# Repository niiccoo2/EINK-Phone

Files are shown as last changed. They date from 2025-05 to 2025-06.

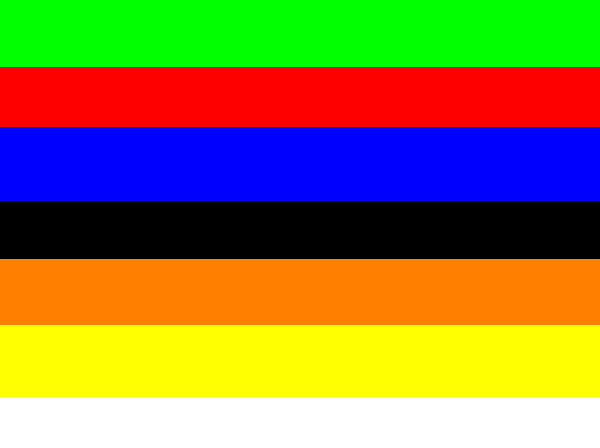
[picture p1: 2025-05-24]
pic/Color7.bmp

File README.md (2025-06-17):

[Google Doc Notes Link](https://docs.google.com/document/d/1l_P9BNs8-fzjLHjxsxwmtQVHC8uADbmZvHsqvaNpZNw/edit?usp=sharing)
[Docs link for pico version](https://docs.google.com/document/d/1WdVnLDW4LZ5mjuCLy1hVp1n7MNubI6F_SzgGbY42siQ/edit?usp=sharing)

### Sunday, May 11:
* Saw the light phone 3 and thought it cost too much.
* Started thinking about how I could make my own

*30 minutes*

### Monday, May 12:
* Decided to use a pi zero w
* Ordered a SIM7600A-H cell modem.

*30 minutes*

### Thursday, May 15:
* Got modem and started working on the python code that sends texts
* Found out that verizon does not work with my modem
* Thought that ssh was slow bc I was using a pi zero *My fault not true*
* Ordered rpi zero 2w
* Ordered a new sim card
* Ordered a 4.2in Waveshare E-Ink screen

*5 hours*

### Saturday, May 17:
* Started figuring out how to use the display drivers in python
* Got the demo working [Photo](https://photos.app.goo.gl/T3E3aoRRHVqETAhi7)
* Got it so that it would display a random number
* Figured out how to use partial refreshes

*4 hours*

### Sunday, May 18:
*Got a basic homescreen working it will dynamically display apps from a dictionary

*3 hours*

### Tuesday, May 20:
*Added a cursor so you can use input statements to move up and down on the screen and select an app. [Photo](https://photos.app.goo.gl/G6LSFMMkUEmNv3iD8)

*3 hours*

### Thursday, May 22:
* Set up new sim card
* FINALLY got the modem working for texting and data
* Hardwired the usb connection because the cable was too big
* [Blog Post](https://niiccoo2.xyz/raspberry-pi-modems/)

*4 hours*

### Friday, May 23:
* Somehow corrupted my pc by thruning on bluetooth, all I wanted was music
* Started working on the first screen of the messages app [Photo](https://photos.app.goo.gl/84rxM1MTwXnvZ23s9)

*4 hours*

### Saturday, May 24:
* Made it so the convos would dynamically display from the JSON file. [Photo](https://photos.app.goo.gl/KQzkmpvL8ekmdxA4A)
* I (Think?) I added scrolling to the convo view today (still has bugs)

*4 hours*

### Sunday, May 25:
* Added the message view
* Made it so it will refresh if you get a new message or send one
* Saves sent and recived messages to the JSON file
* TEXT WRAPPING!!!
* Write text to the left OR the right side of the screen. [Photo](https://photos.app.goo.gl/zQqkJZknWvvdAGR4A)

*6 hours*

### Monday, May 26:
* Made a bad YouTube video about the phone, got almost 3k views for first video

### Thursday, May 29:
* Added scrolling to the message view
* Got idea to make custom PCB for the keyboard

*2 hours*

### Friday, May 30:
* Started learning KiCad and designing the PCB schematic

*5 hours*

### Saturday, May 31:
* HACKNIGHT!
* Worked on the Keyboard pcb a bit

*1 hour*

### Sunday, June 1:
* HACKNIGHT!

### Monday June 2:
* Wired the PCB in KiCad
* Ordered PCB from PcbWay
* Ordered parts from digikey
* Forgot power connecter on PCB (Not the end of the world)

*4 hours*

### Saturday, June 7:
* Tried to get the modem to call my phone, having issues
* Made an account on some b2b site to update firmware.

*2 hours*

# Highway project starts here:
I worked on this a bunch with my own time and money. I got a ok prototype but I'm deciding to change to a custom pcb and using the SIM7000G so that the final device will be much smaller.

### Tuesday, June 17:
* Decided to change from using a pi zero 2 to a pi pico
* Pi pico will use much less power
* Using a SIM7000G modem
* Making a custom PCB

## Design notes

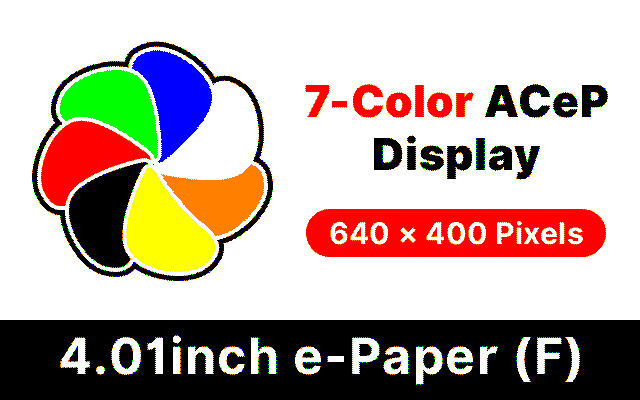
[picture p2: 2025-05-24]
pic/4.01inch-e-Paper.bmp

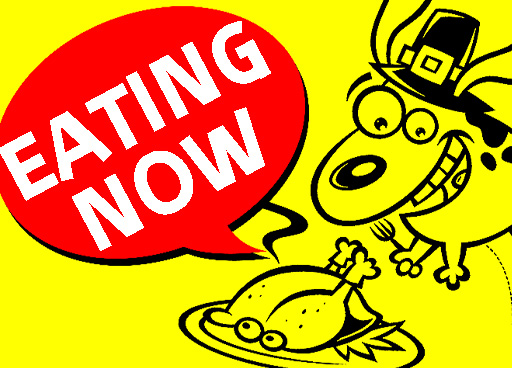
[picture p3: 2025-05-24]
pic/4in37g2.jpg

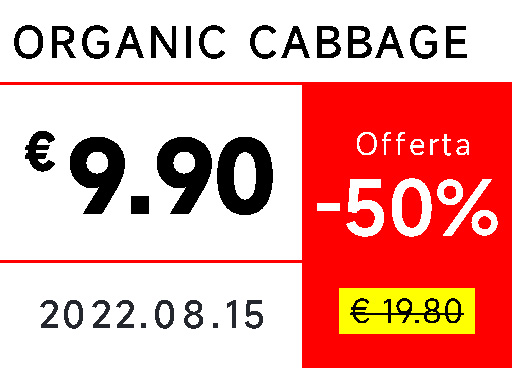
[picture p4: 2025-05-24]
pic/4in37g1.jpg

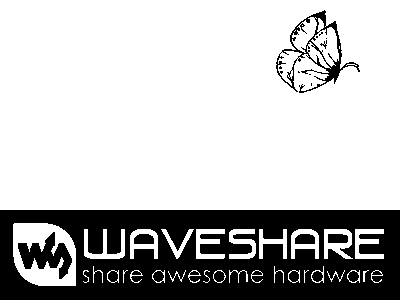
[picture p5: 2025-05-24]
pic/4in2b-b.bmp

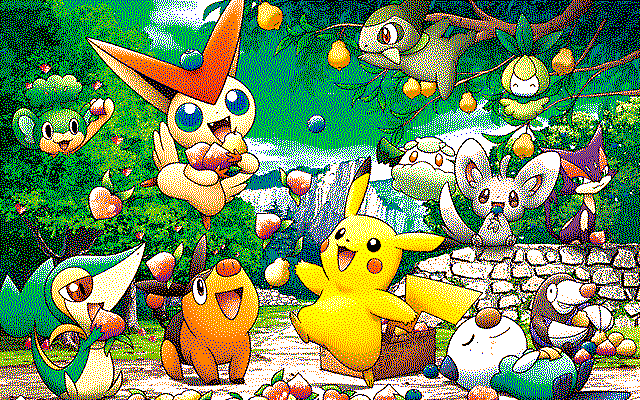
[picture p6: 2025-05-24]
pic/4in01f.bmp

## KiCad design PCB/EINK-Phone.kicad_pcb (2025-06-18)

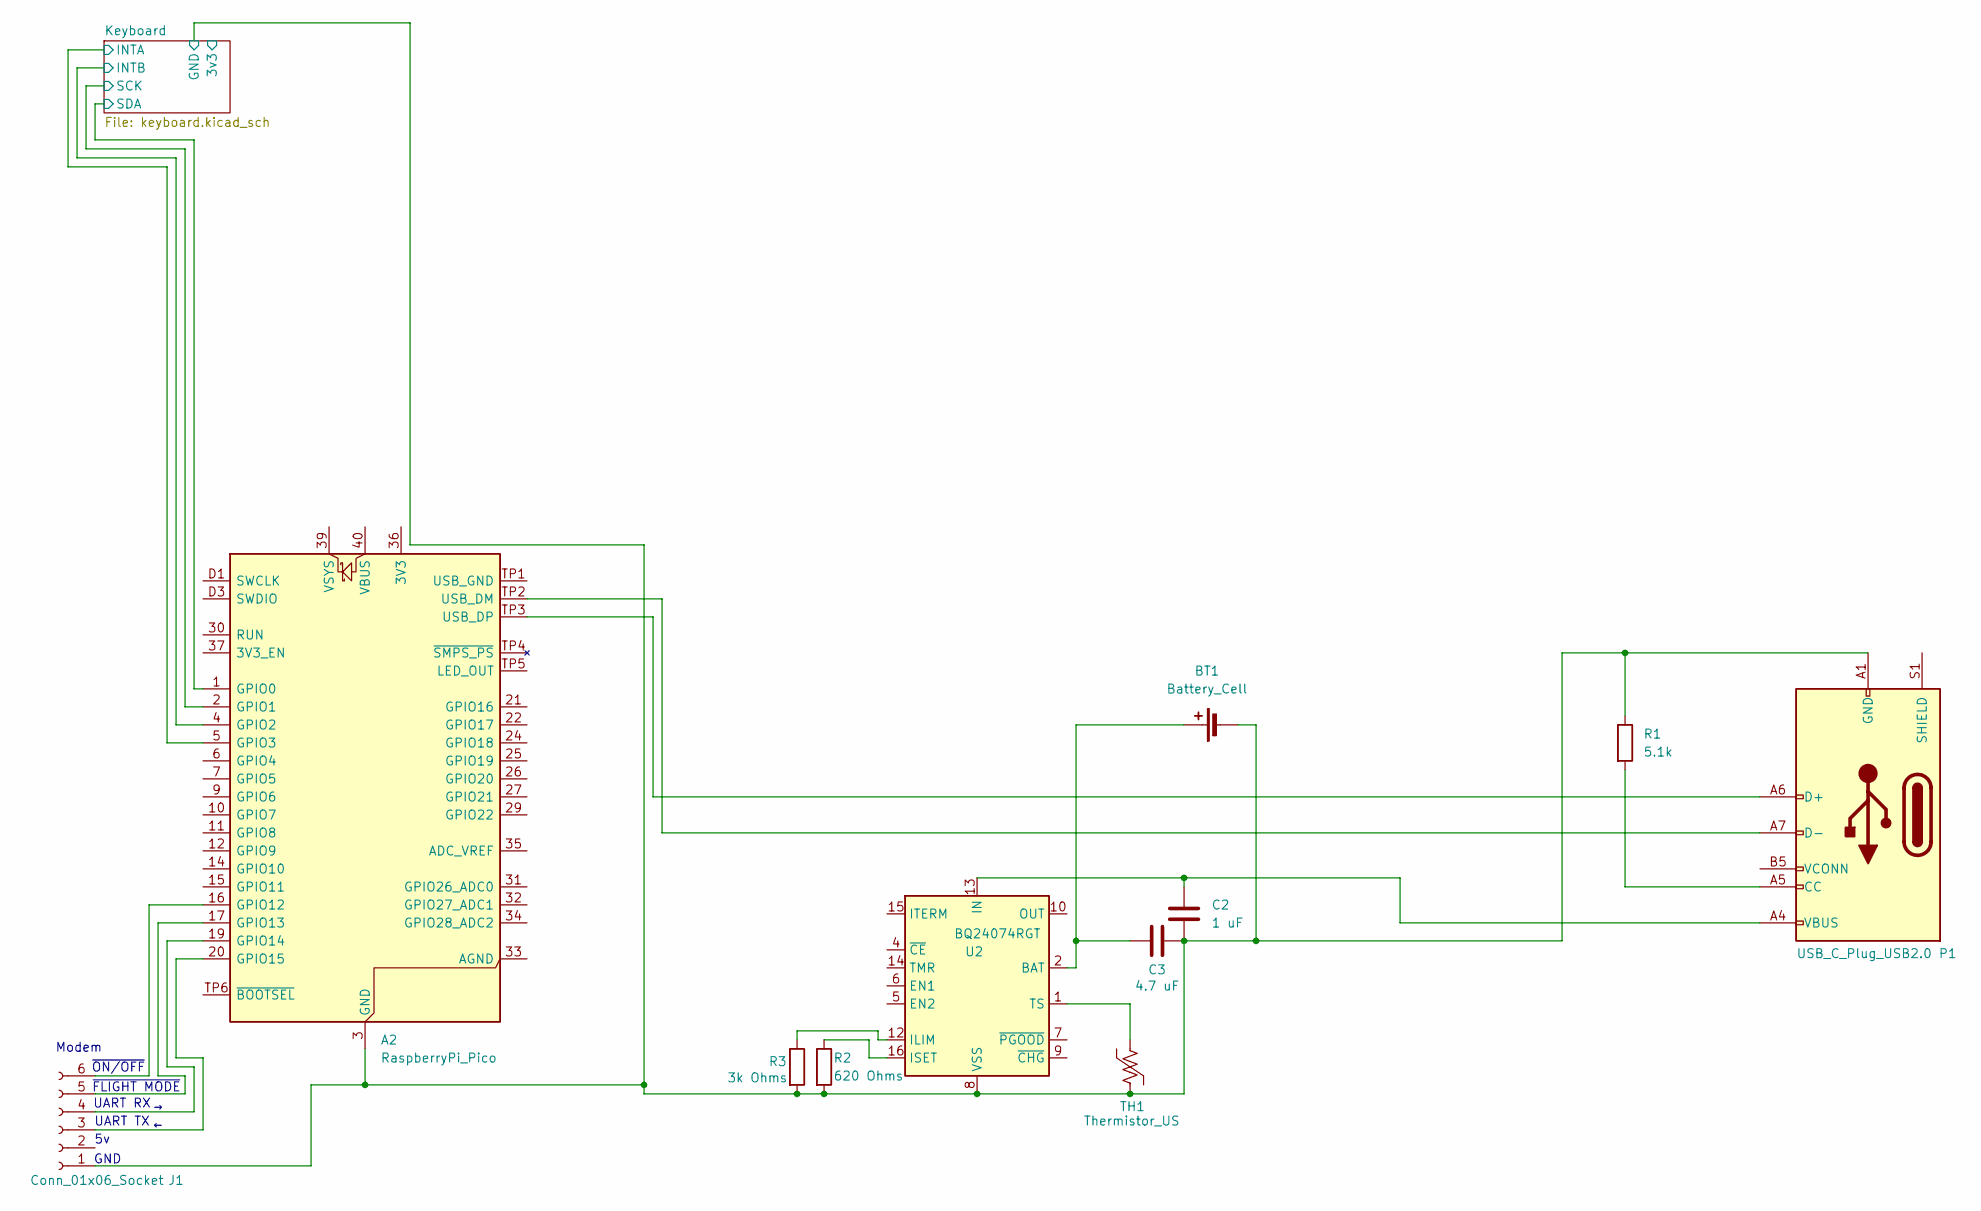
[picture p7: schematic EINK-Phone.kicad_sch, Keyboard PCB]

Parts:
A2: RaspberryPi_Pico; RaspberryPi_Pico_SMD
BT1: Battery_Cell
C2: 1 uF
C3: 4.7 uF
J1: Conn_01x06_Socket
P1: USB_C_Plug_USB2.0
R1: 5.1k
R2: 620 Ohms
R3: 3k Ohms
TH1: Thermistor_US
U2: BQ24074RGT; VQFN-16-1EP_3x3mm_P0.5mm_EP1.6x1.6mm

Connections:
unnamed: A2.16 (GPIO12), J1.6
unnamed: A2.17 (GPIO13), J1.5
unnamed: A2.TP2 (USB_DM), P1.A7 (D-)
unnamed: A2.TP3 (USB_DP), P1.A6 (D+)
unnamed: BT1.1 (+), C3.1, U2.2 (BAT), U2.3 (BAT)
unnamed: C2.1, P1.A4 (VBUS), P1.A9 (VBUS), P1.B4 (VBUS), P1.B9 (VBUS), U2.13 (IN)
unnamed 56: P1.A5 (CC), R1.2; also elsewhere on the board
unnamed 57: J1.2; also elsewhere on the board
unnamed 58: A2.20 (GPIO15), J1.3; also elsewhere on the board
unnamed 59: A2.19 (GPIO14), J1.4; also elsewhere on the board
unnamed: R2.1, U2.16 (ISET)
unnamed: R3.1, U2.12 (ILIM)
unnamed: TH1.1, U2.1 (TS)
unnamed: U2.10 (OUT), U2.11 (OUT)

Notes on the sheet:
Modem
~{ON/OFF}
~{FLIGHT MODE}
UART TX
UART RX
GND

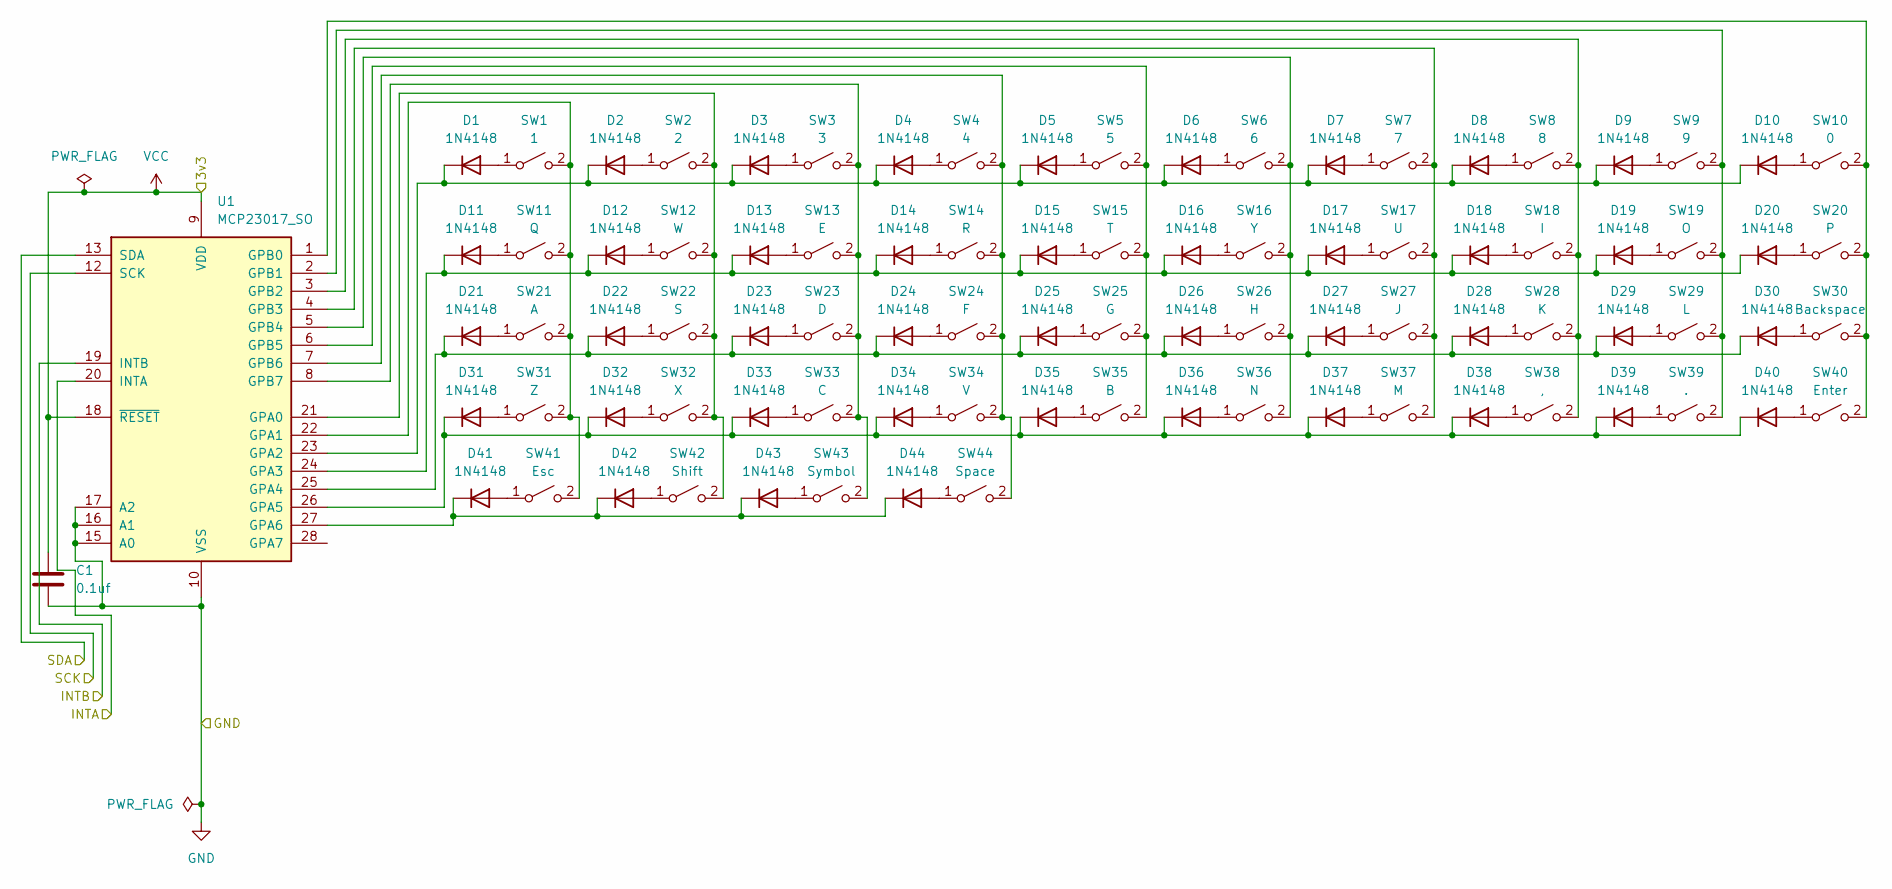
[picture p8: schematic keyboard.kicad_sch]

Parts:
C1: 0.1uf; C_Disc_D5.0mm_W2.5mm_P5.00mm
D1, D2, D3, D4, D5, D6, D7, D8, D9, D10, D11, D12, D13, D14, D15, D16, D17, D18, D19, D20, D21, D22, D23, D24, D25, D26, D27, D28, D29, D30, D31, D32, D33, D34, D35, D36, D37, D38, D39, D40, D41, D42, D43, D44: 1N4148; D_SOD-323_HandSoldering
SW1: 1; SON4_PTS526 SM15 SMTR2 LFS_CNK FLIPPED PINS
SW2: 2; SON4_PTS526 SM15 SMTR2 LFS_CNK FLIPPED PINS
SW3: 3; SON4_PTS526 SM15 SMTR2 LFS_CNK FLIPPED PINS
SW4: 4; SON4_PTS526 SM15 SMTR2 LFS_CNK FLIPPED PINS
SW5: 5; SON4_PTS526 SM15 SMTR2 LFS_CNK FLIPPED PINS
SW6: 6; SON4_PTS526 SM15 SMTR2 LFS_CNK FLIPPED PINS
SW7: 7; SON4_PTS526 SM15 SMTR2 LFS_CNK FLIPPED PINS
SW8: 8; SON4_PTS526 SM15 SMTR2 LFS_CNK FLIPPED PINS
SW9: 9; SON4_PTS526 SM15 SMTR2 LFS_CNK FLIPPED PINS
SW10: 0; SON4_PTS526 SM15 SMTR2 LFS_CNK FLIPPED PINS
SW11: Q; SON4_PTS526 SM15 SMTR2 LFS_CNK FLIPPED PINS
SW12: W; SON4_PTS526 SM15 SMTR2 LFS_CNK FLIPPED PINS
SW13: E; SON4_PTS526 SM15 SMTR2 LFS_CNK FLIPPED PINS
SW14: R; SON4_PTS526 SM15 SMTR2 LFS_CNK FLIPPED PINS
SW15: T; SON4_PTS526 SM15 SMTR2 LFS_CNK FLIPPED PINS
SW16: Y; SON4_PTS526 SM15 SMTR2 LFS_CNK FLIPPED PINS
SW17: U; SON4_PTS526 SM15 SMTR2 LFS_CNK FLIPPED PINS
SW18: I; SON4_PTS526 SM15 SMTR2 LFS_CNK FLIPPED PINS
SW19: O; SON4_PTS526 SM15 SMTR2 LFS_CNK FLIPPED PINS
SW20: P; SON4_PTS526 SM15 SMTR2 LFS_CNK FLIPPED PINS
SW21: A; SON4_PTS526 SM15 SMTR2 LFS_CNK FLIPPED PINS
SW22: S; SON4_PTS526 SM15 SMTR2 LFS_CNK FLIPPED PINS
SW23: D; SON4_PTS526 SM15 SMTR2 LFS_CNK FLIPPED PINS
SW24: F; SON4_PTS526 SM15 SMTR2 LFS_CNK FLIPPED PINS
SW25: G; SON4_PTS526 SM15 SMTR2 LFS_CNK FLIPPED PINS
SW26: H; SON4_PTS526 SM15 SMTR2 LFS_CNK FLIPPED PINS
SW27: J; SON4_PTS526 SM15 SMTR2 LFS_CNK FLIPPED PINS
SW28: K; SON4_PTS526 SM15 SMTR2 LFS_CNK FLIPPED PINS
SW29: L; SON4_PTS526 SM15 SMTR2 LFS_CNK FLIPPED PINS
SW30: Backspace; SON4_PTS526 SM15 SMTR2 LFS_CNK FLIPPED PINS
SW31: Z; SON4_PTS526 SM15 SMTR2 LFS_CNK FLIPPED PINS
SW32: X; SON4_PTS526 SM15 SMTR2 LFS_CNK FLIPPED PINS
SW33: C; SON4_PTS526 SM15 SMTR2 LFS_CNK FLIPPED PINS
SW34: V; SON4_PTS526 SM15 SMTR2 LFS_CNK FLIPPED PINS
SW35: B; SON4_PTS526 SM15 SMTR2 LFS_CNK FLIPPED PINS
SW36: N; SON4_PTS526 SM15 SMTR2 LFS_CNK FLIPPED PINS
SW37: M; SON4_PTS526 SM15 SMTR2 LFS_CNK FLIPPED PINS
SW38: ,; SON4_PTS526 SM15 SMTR2 LFS_CNK FLIPPED PINS
SW39: .; SON4_PTS526 SM15 SMTR2 LFS_CNK FLIPPED PINS
SW40: Enter; SON4_PTS526 SM15 SMTR2 LFS_CNK FLIPPED PINS
SW41: Esc; SON4_PTS526 SM15 SMTR2 LFS_CNK FLIPPED PINS
SW42: Shift; SON4_PTS526 SM15 SMTR2 LFS_CNK FLIPPED PINS
SW43: Symbol; SON4_PTS526 SM15 SMTR2 LFS_CNK FLIPPED PINS
SW44: Space; SON4_PTS526 SM15 SMTR2 LFS_CNK FLIPPED PINS
U1: MCP23017_SO; SOIC-28W_7.5x17.9mm_P1.27mm

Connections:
GND: C1.2, U1.10 (VSS), U1.15 (A0), U1.16 (A1), U1.17 (A2); also elsewhere on the board
unnamed: D1.2 (A), SW1.1 (A)
unnamed: D1.1 (K), D2.1 (K), D3.1 (K), D4.1 (K), D5.1 (K), D6.1 (K), D7.1 (K), D8.1 (K), D9.1 (K), D10.1 (K), U1.23 (GPA2)
unnamed: D2.2 (A), SW2.1 (A)
unnamed: D3.2 (A), SW3.1 (A)
unnamed: D4.2 (A), SW4.1 (A)
unnamed: D5.2 (A), SW5.1 (A)
unnamed: D6.2 (A), SW6.1 (A)
unnamed: D7.2 (A), SW7.1 (A)
unnamed: D8.2 (A), SW8.1 (A)
unnamed: D9.2 (A), SW9.1 (A)
unnamed: D10.2 (A), SW10.1 (A)
unnamed: D11.2 (A), SW11.1 (A)
unnamed: D11.1 (K), D12.1 (K), D13.1 (K), D14.1 (K), D15.1 (K), D16.1 (K), D17.1 (K), D18.1 (K), D19.1 (K), D20.1 (K), U1.24 (GPA3)
unnamed: D12.2 (A), SW12.1 (A)
unnamed: D13.2 (A), SW13.1 (A)
unnamed: D14.2 (A), SW14.1 (A)
unnamed: D15.2 (A), SW15.1 (A)
unnamed: D16.2 (A), SW16.1 (A)
unnamed: D17.2 (A), SW17.1 (A)
unnamed: D18.2 (A), SW18.1 (A)
unnamed: D19.2 (A), SW19.1 (A)
unnamed: D20.2 (A), SW20.1 (A)
unnamed: D21.2 (A), SW21.1 (A)
unnamed: D21.1 (K), D22.1 (K), D23.1 (K), D24.1 (K), D25.1 (K), D26.1 (K), D27.1 (K), D28.1 (K), D29.1 (K), D30.1 (K), U1.25 (GPA4)
unnamed: D22.2 (A), SW22.1 (A)
unnamed: D23.2 (A), SW23.1 (A)
unnamed: D24.2 (A), SW24.1 (A)
unnamed: D25.2 (A), SW25.1 (A)
unnamed: D26.2 (A), SW26.1 (A)
unnamed: D27.2 (A), SW27.1 (A)
unnamed: D28.2 (A), SW28.1 (A)
unnamed: D29.2 (A), SW29.1 (A)
unnamed: D30.2 (A), SW30.1 (A)
unnamed: D31.2 (A), SW31.1 (A)
unnamed: D31.1 (K), D32.1 (K), D33.1 (K), D34.1 (K), D35.1 (K), D36.1 (K), D37.1 (K), D38.1 (K), D39.1 (K), D40.1 (K), U1.26 (GPA5)
unnamed: D32.2 (A), SW32.1 (A)
unnamed: D33.2 (A), SW33.1 (A)
unnamed: D34.2 (A), SW34.1 (A)
unnamed: D35.2 (A), SW35.1 (A)
unnamed: D36.2 (A), SW36.1 (A)
unnamed: D37.2 (A), SW37.1 (A)
unnamed: D38.2 (A), SW38.1 (A)
unnamed: D39.2 (A), SW39.1 (A)
unnamed: D40.2 (A), SW40.1 (A)
unnamed: D41.2 (A), SW41.1 (A)
unnamed: D41.1 (K), D42.1 (K), D43.1 (K), D44.1 (K), U1.27 (GPA6)
unnamed: D42.2 (A), SW42.1 (A)
unnamed: D43.2 (A), SW43.1 (A)
unnamed: D44.2 (A), SW44.1 (A)
unnamed 57: U1.19 (INTB); also elsewhere on the board
unnamed 58: U1.12 (SCK); also elsewhere on the board
unnamed 59: U1.13 (SDA); also elsewhere on the board
unnamed: SW1.2 (B), SW11.2 (B), SW21.2 (B), SW31.2 (B), SW41.2 (B), U1.22 (GPA1)
unnamed: SW10.2 (B), SW20.2 (B), SW30.2 (B), SW40.2 (B), U1.1 (GPB0)
unnamed: SW2.2 (B), SW12.2 (B), SW22.2 (B), SW32.2 (B), SW42.2 (B), U1.21 (GPA0)
unnamed: SW3.2 (B), SW13.2 (B), SW23.2 (B), SW33.2 (B), SW43.2 (B), U1.8 (GPB7)
unnamed: SW4.2 (B), SW14.2 (B), SW24.2 (B), SW34.2 (B), SW44.2 (B), U1.7 (GPB6)
unnamed: SW5.2 (B), SW15.2 (B), SW25.2 (B), SW35.2 (B), U1.6 (GPB5)
unnamed: SW6.2 (B), SW16.2 (B), SW26.2 (B), SW36.2 (B), U1.5 (GPB4)
unnamed: SW7.2 (B), SW17.2 (B), SW27.2 (B), SW37.2 (B), U1.4 (GPB3)
unnamed: SW8.2 (B), SW18.2 (B), SW28.2 (B), SW38.2 (B), U1.3 (GPB2)
unnamed: SW9.2 (B), SW19.2 (B), SW29.2 (B), SW39.2 (B), U1.2 (GPB1)
VCC: C1.1, U1.9 (VDD), U1.18 (~RESET)

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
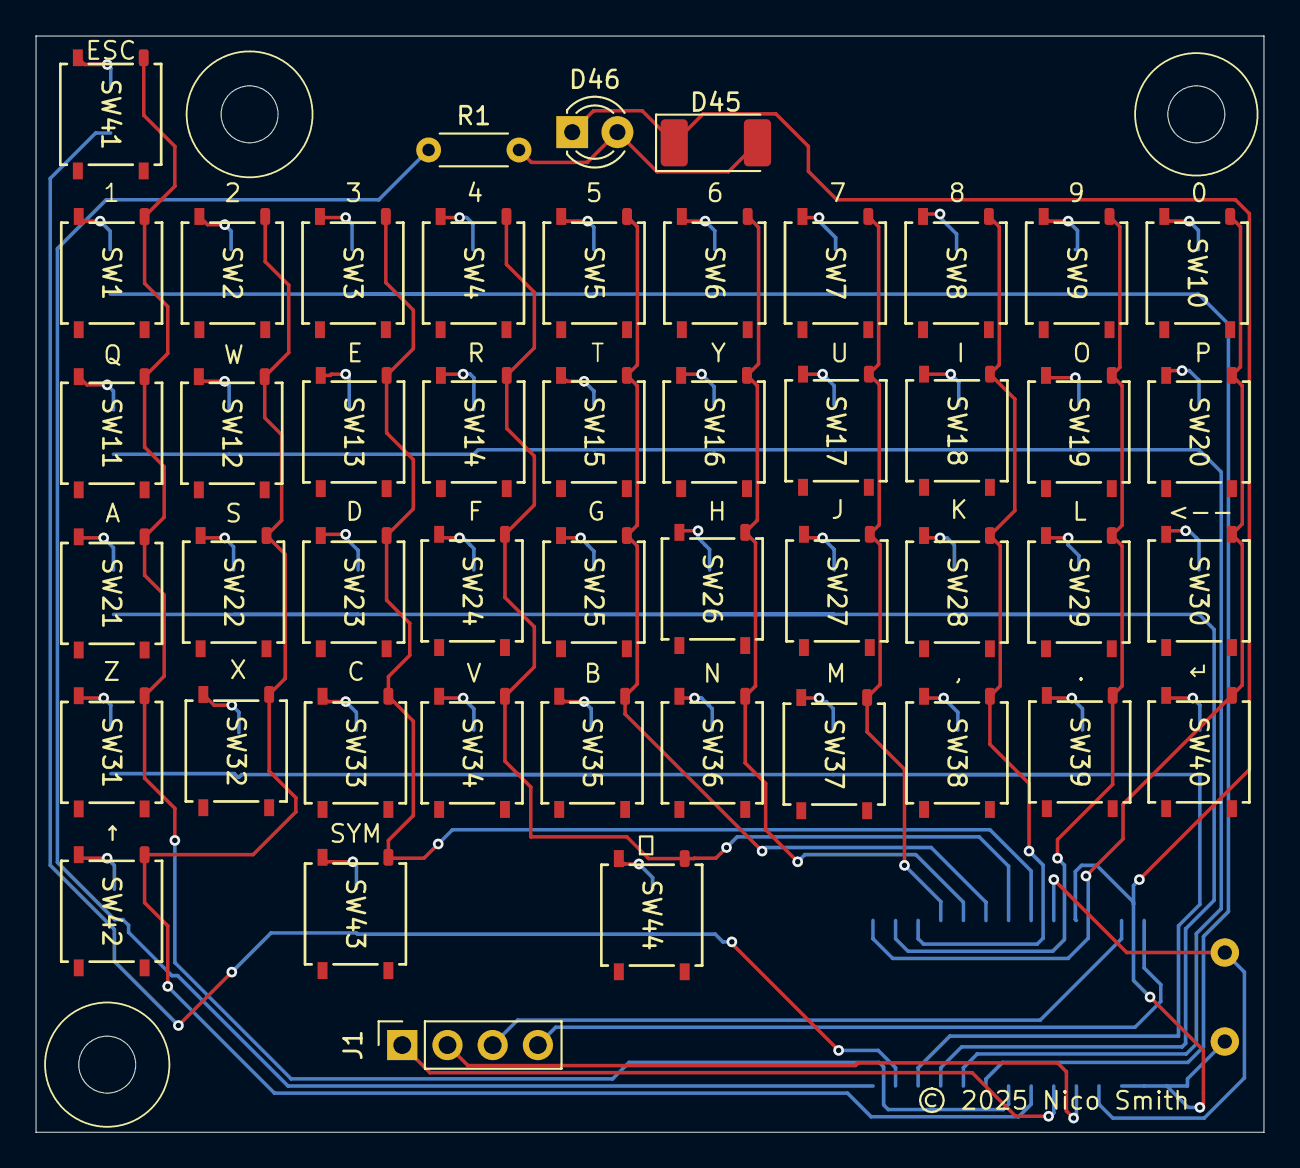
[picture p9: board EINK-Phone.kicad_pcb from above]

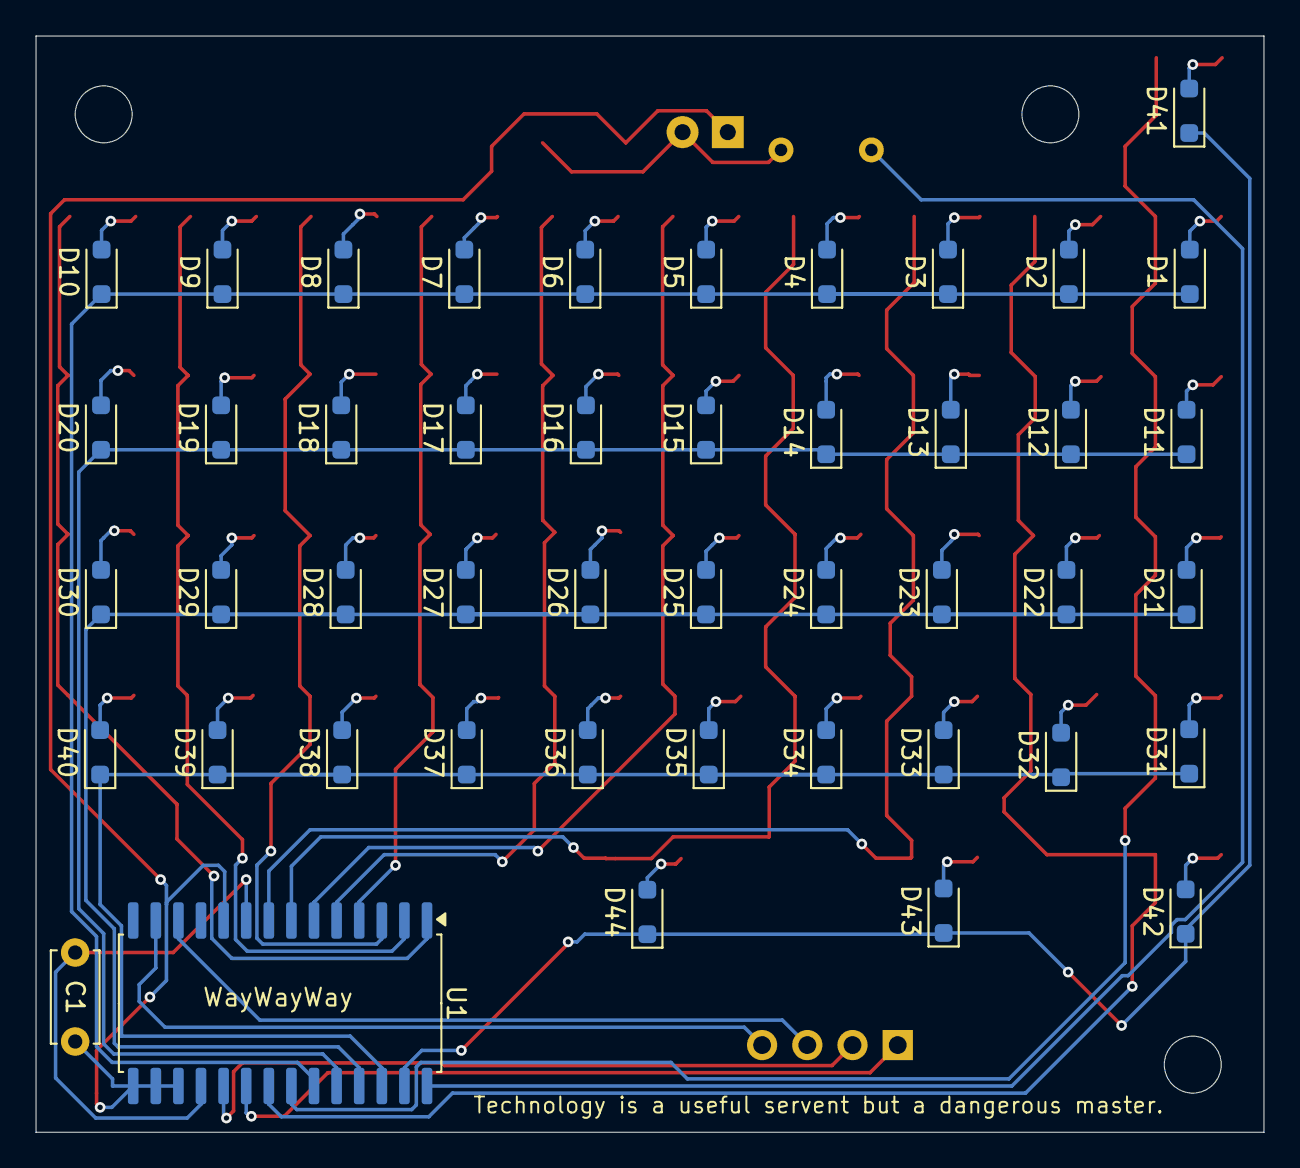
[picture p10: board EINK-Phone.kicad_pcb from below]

Board: 2 copper layers, 69.0 x 61.6 mm, 94 parts (46 on the bottom side), 67 nets.

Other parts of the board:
D45: LED; LED_2010_5025Metric_Pad1.52x2.65mm_HandSolder
D46: LED; LED_D3.0mm

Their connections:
GND: D45.1 (K), D46.1 (K); also elsewhere on the board
unnamed 56: D45.2 (A), D46.2 (A); also elsewhere on the board

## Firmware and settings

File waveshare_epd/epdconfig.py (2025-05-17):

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

import os
import logging
import sys
import time
import subprocess

from ctypes import *

logger = logging.getLogger(__name__)


class RaspberryPi:
    # Pin definition
    RST_PIN  = 17
    DC_PIN   = 25
    CS_PIN   = 8
    BUSY_PIN = 24
    PWR_PIN  = 18
    MOSI_PIN = 10
    SCLK_PIN = 11

    def __init__(self):
        import spidev
        import gpiozero
        
        self.SPI = spidev.SpiDev()
        self.GPIO_RST_PIN    = gpiozero.LED(self.RST_PIN)
        self.GPIO_DC_PIN     = gpiozero.LED(self.DC_PIN)
        # self.GPIO_CS_PIN     = gpiozero.LED(self.CS_PIN)
        self.GPIO_PWR_PIN    = gpiozero.LED(self.PWR_PIN)
        self.GPIO_BUSY_PIN   = gpiozero.Button(self.BUSY_PIN, pull_up = False)

        

    def digital_write(self, pin, value):
        if pin == self.RST_PIN:
            if value:
                self.GPIO_RST_PIN.on()
            else:
                self.GPIO_RST_PIN.off()
        elif pin == self.DC_PIN:
            if value:
                self.GPIO_DC_PIN.on()
            else:
                self.GPIO_DC_PIN.off()
        # elif pin == self.CS_PIN:
        #     if value:
        #         self.GPIO_CS_PIN.on()
        #     else:
        #         self.GPIO_CS_PIN.off()
        elif pin == self.PWR_PIN:
            if value:
                self.GPIO_PWR_PIN.on()
            else:
                self.GPIO_PWR_PIN.off()

    def digital_read(self, pin):
        if pin == self.BUSY_PIN:
            return self.GPIO_BUSY_PIN.value
        elif pin == self.RST_PIN:
            return self.RST_PIN.value
        elif pin == self.DC_PIN:
            return self.DC_PIN.value
        # elif pin == self.CS_PIN:
        #     return self.CS_PIN.value
        elif pin == self.PWR_PIN:
            return self.PWR_PIN.value

    def delay_ms(self, delaytime):
        time.sleep(delaytime / 1000.0)

    def spi_writebyte(self, data):
        self.SPI.writebytes(data)

    def spi_writebyte2(self, data):
        self.SPI.writebytes2(data)

    def DEV_SPI_write(self, data):
        self.DEV_SPI.DEV_SPI_SendData(data)

    def DEV_SPI_nwrite(self, data):
        self.DEV_SPI.DEV_SPI_SendnData(data)

    def DEV_SPI_read(self):
        return self.DEV_SPI.DEV_SPI_ReadData()

    def module_init(self, cleanup=False):
        self.GPIO_PWR_PIN.on()
        
        if cleanup:
            find_dirs = [
                os.path.dirname(os.path.realpath(__file__)),
                '/usr/local/lib',
                '/usr/lib',
            ]
            self.DEV_SPI = None
            for find_dir in find_dirs:
                val = int(os.popen('getconf LONG_BIT').read())
                logging.debug("System is %d bit"%val)
                if val == 64:
                    so_filename = os.path.join(find_dir, 'DEV_Config_64.so')
                else:
                    so_filename = os.path.join(find_dir, 'DEV_Config_32.so')
                if os.path.exists(so_filename):
                    self.DEV_SPI = CDLL(so_filename)
                    break
            if self.DEV_SPI is None:
                RuntimeError('Cannot find DEV_Config.so')

            self.DEV_SPI.DEV_Module_Init()

        else:
            # SPI device, bus = 0, device = 0
            self.SPI.open(0, 0)
            self.SPI.max_speed_hz = 4000000
            self.SPI.mode = 0b00
        return 0

    def module_exit(self, cleanup=False):
        logger.debug("spi end")
        self.SPI.close()

        self.GPIO_RST_PIN.off()
        self.GPIO_DC_PIN.off()
        self.GPIO_PWR_PIN.off()
        logger.debug("close 5V, Module enters 0 power consumption ...")
        
        if cleanup:
            self.GPIO_RST_PIN.close()
            self.GPIO_DC_PIN.close()
            # self.GPIO_CS_PIN.close()
            self.GPIO_PWR_PIN.close()
            self.GPIO_BUSY_PIN.close()
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

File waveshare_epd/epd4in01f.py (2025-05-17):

#!/usr/bin/python
# -*- coding:utf-8 -*-
# *****************************************************************************
# * | File        :	  epd4in01f.py
# * | Author      :   Waveshare team
# * | Function    :   Electronic paper driver
# * | Info        :
# *----------------
# * | This version:   V1.1
# * | Date        :   2022-08-10
# # | Info        :   python demo
# -----------------------------------------------------------------------------
# Permission is hereby granted, free of charge, to any person obtaining a copy
# of this software and associated documnetation files (the "Software"), to deal
# in the Software without restriction, including without limitation the rights
# to use, copy, modify, merge, publish, distribute, sublicense, and/or sell
# copies of the Software, and to permit persons to  whom the Software is
# furished to do so, subject to the following conditions:
#
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

import logging
from . import epdconfig

# Display resolution
EPD_WIDTH       = 640
EPD_HEIGHT      = 400

logger = logging.getLogger(__name__)

class EPD:
    def __init__(self):
        self.reset_pin = epdconfig.RST_PIN
        self.dc_pin = epdconfig.DC_PIN
        self.busy_pin = epdconfig.BUSY_PIN
        self.cs_pin = epdconfig.CS_PIN
        self.width = EPD_WIDTH
        self.height = EPD_HEIGHT
        self.BLACK  = 0x000000   #   0000  BGR
        self.WHITE  = 0xffffff   #   0001
        self.GREEN  = 0x00ff00   #   0010
        self.BLUE   = 0xff0000   #   0011
        self.RED    = 0x0000ff   #   0100
        self.YELLOW = 0x00ffff   #   0101
        self.ORANGE = 0x0080ff   #   0110
        
        
    # Hardware reset
    def reset(self):
        epdconfig.digital_write(self.reset_pin, 1)
        epdconfig.delay_ms(200)
        epdconfig.digital_write(self.reset_pin, 0)
        epdconfig.delay_ms(1)
        epdconfig.digital_write(self.reset_pin, 1)
        epdconfig.delay_ms(200)

    def send_command(self, command):
        epdconfig.digital_write(self.dc_pin, 0)
        epdconfig.digital_write(self.cs_pin, 0)
        epdconfig.spi_writebyte([command])
        epdconfig.digital_write(self.cs_pin, 1)

    def send_data(self, data):
        epdconfig.digital_write(self.dc_pin, 1)
        epdconfig.digital_write(self.cs_pin, 0)
        epdconfig.spi_writebyte([data])
        epdconfig.digital_write(self.cs_pin, 1)

    # send a lot of data   
    def send_data2(self, data):
        epdconfig.digital_write(self.dc_pin, 1)
        epdconfig.digital_write(self.cs_pin, 0)
        epdconfig.spi_writebyte2(data)
        epdconfig.digital_write(self.cs_pin, 1)
        
    def ReadBusyHigh(self):
        logger.debug("e-Paper busy")
        while(epdconfig.digital_read(self.busy_pin) == 0):      # 0: idle, 1: busy
            epdconfig.delay_ms(10)
        logger.debug("e-Paper busy release")
        
    def ReadBusyLow(self):
        logger.debug("e-Paper busy")
        while(epdconfig.digital_read(self.busy_pin) == 1):      # 0: idle, 1: busy
            epdconfig.delay_ms(10)    
        logger.debug("e-Paper busy release")
        
    def init(self):
        if (epdconfig.module_init() != 0):
            return -1
        # EPD hardware init start
        self.reset()
        
        self.ReadBusyHigh()
        self.send_command(0x00)
        self.send_data(0x2f)
        self.send_data(0x00)
        self.send_command(0x01)
        self.send_data(0x37)
        self.send_data(0x00)
        self.send_data(0x05)
        self.send_data(0x05)
        self.send_command(0x03)
        self.send_data(0x00)
        self.send_command(0x06)
        self.send_data(0xC7)
        self.send_data(0xC7)
        self.send_data(0x1D)
        self.send_command(0x41)
        self.send_data(0x00)
        self.send_command(0x50)
        self.send_data(0x37)
        self.send_command(0x60)
        self.send_data(0x22)
        self.send_command(0x61)
        self.send_data(0x02)
        self.send_data(0x80)
        self.send_data(0x01)
        self.send_data(0x90)
        self.send_command(0xE3)
        self.send_data(0xAA)
        
        # EPD hardware init end
        return 0
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

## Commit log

2025-05-22 I was on wrong device
2025-06-18 Added KiCad data
    [keyboard.kicad_sch, messenger.kicad_pcb, messenger.kicad_sch]
2025-06-18 Replace Messenger PCB files with EINK-Phone PCB project
    Remove Messenger PCB design and backup files, and add new EINK-Phone KiCad project files to transition development focus to the EINK-Phone hardware.
    [EINK-Phone.kicad_pcb, EINK-Phone.kicad_sch, messenger.kicad_sch]
2025-06-18 Add thermistor symbol to schematic; remove old backups and project file
    - Added "Device:Thermistor_US" symbol to EINK-Phone.kicad_sch for temperature sensing support
    - Deleted outdated backup ZIP and messenger.kicad_pro project file
    - Prepared new backup directory for updated project structure
    [EINK-Phone.kicad_sch]
2025-06-20 Increase maxBuffer size to prevent stdout overflow errors
    [EINK-Phone.kicad_pcb, EINK-Phone.kicad_sch, keyboard.kicad_sch]
2025-06-20 Add fp-info-cache to track footprint information in PCB directory.

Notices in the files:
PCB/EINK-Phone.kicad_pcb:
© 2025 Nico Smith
